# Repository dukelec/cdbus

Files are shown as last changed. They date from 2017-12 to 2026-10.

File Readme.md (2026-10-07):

[//]: # (IP Core for CDBUS Protocol)

CDBUS IP Core
=======================================
(This is the 8-bit version; for the 32-bit version, please switch to the corresponding branch.)

1. [CDBUS Protocol](#cdbus-protocol)
2. [Block Diagram](#block-diagram)
3. [Registers](#registers)
4. [Interface](#interface)
5. [Examples](#examples)
6. [Simulation](#simulation)
7. [Ready-to-Use Devices](#ready-to-use-devices)
8. [License](#license)

CDBUS is a simple protocol designed for serial ports and serial bus communication, commonly employed in RS-485 buses.
It utilizes hardware arbitration and other mechanisms to avoid data conflicts, allowing nodes to freely transmit and receive data packets,
thereby overcoming the limitations of single-master polling.

## CDBUS Protocol

CDBUS has a 3-byte header: `[src_addr, dst_addr, data_len]`, followed by user data, and concluding with a 2-byte CRC (identical to MODBUS CRC).

The CDBUS protocol at the byte level can be directly used for traditional serial communication,
such as traditional UART, RS-232, RS-485, and USB virtual serial ports.

The full CDBUS protocol at the bit level requires dedicated hardware controllers (or software emulation)
to achieve conflict avoidance, higher speeds, and strong real-time performance.

### Arbitration Mode (CDBUS-A)

* Introduces an arbitration mechanism, similar to the CAN bus, to automatically avoid conflicts.
* Supports dual baud rates for high-speed communication;
  the maximum baud rate of the high-speed phase is `sysclk` ÷ 3 (e.g. 50 Mbps for 150 MHz `sysclk`).
* Supports unicast, multicast and broadcast.
* The maximum user data size is 253 bytes.
* Hardware packing, unpacking, verification and filtering, reducing CPU load and development effort.
* Compatible with traditional RS-485 hardware (the arbitration function remains effective).

The protocol timing example, consisting of only one byte of user data:  
(You can configure the lengths of idle time and transmission permit time.)

protocol

Tips:
 - When a high-priority node needs to send unimportant data, its transmission permit time (TX_PERMIT_LEN) can be dynamically increased.

Arbitration example:

arbitration

Example waveforms for TX output and TX_EN pins:

arbitration

The RX data sampling point is at 1/2 bit; for TX readback, it's at 3/4 bit.

Lower-priority nodes back off during arbitration and retransmit after the bus is idle, until successful or cancelled by
the user.

### Break Sync Mode (CDBUS-BS)

In CDBUS-A mode, if the low-speed portion takes too long, it can become a bottleneck for communication efficiency.

To address this, single-rate peer-to-peer bus communication can be achieved using CDBUS-BS mode:

 - Different nodes have different configurations for the TX_PERMIT_LEN parameter, requiring sufficiently large differences to avoid conflicts.
 - If any node has pending data frames waiting to be sent before the transmission permit point, transmission starts from that point.
 - Otherwise, wait until the idle time exceeds MAX_IDLE_LEN. When there are pending data frames waiting for transmission,
   first send a break character to bring the bus out of the idle state.

arbitration

The CDBUS-BS mode is suitable for high-speed applications with few nodes, and is also well-suited to software implementation.

### Transparent Mode

For protocols other than CDBUS over a plain UART (8N1 only), e.g. MODBUS RTU,
the controller can pass raw frames through without header;
it works with the traditional half-duplex mode and the full-duplex mode, set DIV_HS equal to DIV_LS and keep FILTER at 0xff.
The CRC of CDBUS is the same as MODBUS, so the CRC is still appended and checked by hardware unless `CRC maintained by user` is set.

RX: bytes are collected into a page (up to 256 bytes), which is committed when the bus is idle for IDLE_WAIT_LEN;
RX_LEN is the byte count minus one. A frame with CRC error or longer than 256 bytes is dropped and flagged
like a broken CDBUS frame, or saved with `save broken frame` set (the page of an over-long frame is incomplete).
A single byte is dropped as noise.
In half-duplex mode, the echo of the own transmission is dropped unless the loopback bit is set.

TX: the page layout is the same as a CDBUS frame, `[reserved, reserved, data_len, data...]`, only the data (up to 253 bytes)
and the CRC are sent; with `CRC maintained by user`, the last two bytes come from the page as well,
data_len can still be 253: the bytes beyond the end of the page wrap around to the reserved bytes at the start.
The idle time between frames is IDLE_WAIT_LEN (half-duplex, if RX sees TX) plus TX_PERMIT_LEN plus TX_PRE_LEN,
which must be longer than the IDLE_WAIT_LEN of the receiver.

## Block Diagram

block_diagram

#### Operation

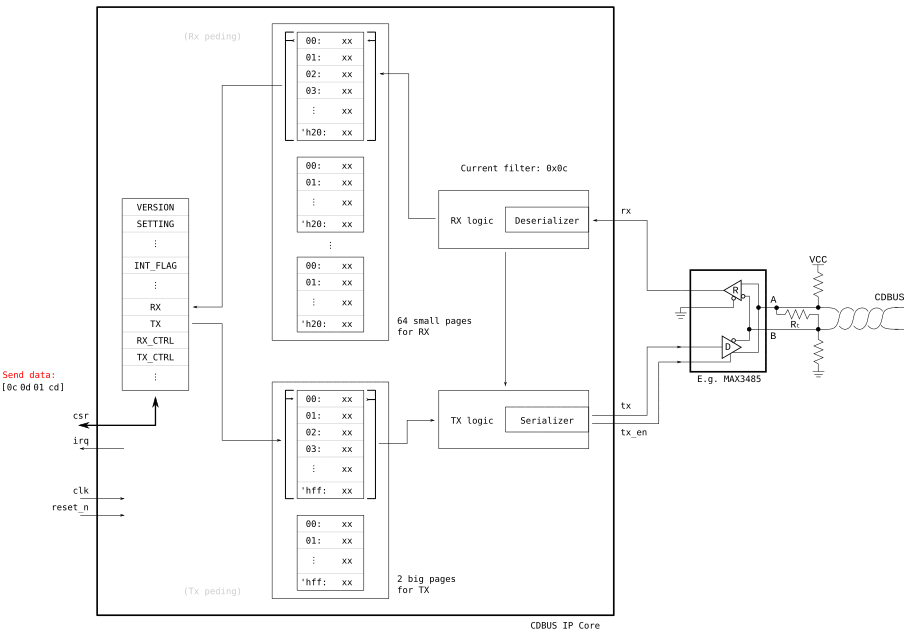
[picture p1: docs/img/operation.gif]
operation


## Registers

| Register Name |  Addr | Access | Default | Description (8-bit width by default if not specified)|
|---|---|---|---|---|
| VERSION |  0x00 | RD | 0x0f | Hardware version |
| SETTING |  0x02 | RD/WR  | 0x01 | Configuration |
| PIN_CFG |  0x03 | RD/WR  | 0x00 | Pin configuration |
| IDLE_WAIT_LEN |  0x04 | RD/WR  | 0x0a | Idle entry wait time |
| TX_PERMIT_LEN_L |  0x05 | RD/WR  | 0x14 | TX permit wait time (10 bits) |
| TX_PERMIT_LEN_H |  0x06 | RD/WR  | 0x00 | |
| MAX_IDLE_LEN_L |  0x07 | RD/WR  | 0xc8 | Max idle wait time, BS mode (10 bits) |
| MAX_IDLE_LEN_H |  0x08 | RD/WR  | 0x00 | |
| TX_PRE_LEN |  0x09 | RD/WR  | 0x01 | TX_EN pre-assert time (2 bits) |
| FILTER |  0x0b | RD/WR  | 0xff | Local address |
| DIV_LS_L |  0x0c | RD/WR  | 0x5a | Low-speed rate setting (16 bits) |
| DIV_LS_H |  0x0d | RD/WR  | 0x01 | |
| DIV_HS_L |  0x0e | RD/WR  | 0x5a | High-speed rate setting (16 bits) |
| DIV_HS_H |  0x0f | RD/WR  | 0x01 | |
| INT_MASK_L |  0x10 | RD/WR  | 0x00 | Interrupt mask (16 bits) |
| INT_MASK_H |  0x11 | RD/WR  | 0x00 | |
| INT_FLAG_L |  0x12 | RD | n/a | Status (16 bits) |
| INT_FLAG_H |  0x13 | RD | n/a | |
| RX_LEN |  0x14 | RD | n/a | Data length of the frame to be read, or frame_len - 1 |
| DAT |  0x15 | RD/WR  | n/a | Read & Write RX page |
| CTRL |  0x16 | WR | n/a | RX & TX control |
| DAT_HOLD |  0x17 | RD/WR  | n/a | Same as DAT, but keeps the page open |
| RX_ADDR |  0x18 | WR | n/a | Set the read position of the RX page |
| FILTER_M0 |  0x1a | RD/WR  | 0xff | Multicast filter0 |
| FILTER_M1 |  0x1b | RD/WR  | 0xff | Multicast filter1 |
| FILTER_MSK0 |  0x1c | RD/WR  | 0xff | Multicast mask0 |
| FILTER_MSK1 |  0x1d | RD/WR  | 0xff | Multicast mask1 |

To write a register with more than 8 bits, first write the high byte followed by the low byte.
The high byte can be omitted if it is 0.

Time unit: one bit period at the low-speed baud rate.

**SETTING:**

| FIELD | DESCRIPTION |
|--- |---|
| [5] | Save broken frame |
| [4] | CRC maintained by user |
| [3] | Transparent mode: keep own TX echo (loopback) |
| [2] | Transparent mode |
| [1:0] | Mode selection |

| [1] | [0] | DESCRIPTION |
|-----|-----|---|
| 0 | 0 | Traditional half-duplex mode |
| 0 | 1 | CDBUS-A mode (default) |
| 1 | 0 | CDBUS-BS mode |
| 1 | 1 | Full-duplex mode |

Transparent mode only works with mode 00 and 11.

**PIN_CFG:**

| FIELD | DESCRIPTION |
|--- |---|
| [3] | RX pin inversion |
| [2] | TX pin inversion |
| [1] | TX stays low for arbitration and break character  |
| [0] | Enable push-pull output for TX and TX_EN pin |

**TX_PRE_LEN:**

Example waveforms for TX output and TX_EN pins (TX_PRE_LEN = 1 bit):

arbitration

Not used in arbitration mode, nor for the break character automatically generated in BS mode.

**FILTERS:**

block_diagram

Addresses other than 255 may be used as multicast addresses.

**DIV_xx_x:**

Baud rate divider value:
DIV_xx[15:0] = sysclk ÷ baud_rate − 1

The minimum value is 2.

For single-rate operation, set DIV_HS to the same value as DIV_LS.

**INT_MASK:**

Output of irq = ((INT_FLAG & INT_MASK) != 0).

**INT_FLAG:**

| FIELD | DESCRIPTION |
|--- |---|
| [15] | 1: Bus not idle |
| [14] | 1: Bus idle |
| [13:8]  | Number of RX pages to read |
| [7] | 1: TX error (TX low, RX sampled high) |
| [6] | 1: TX collision detected |
| [5] | 1: TX page released by hardware |
| [4] | 1: Empty TX page available |
| [3] | 1: RX error (frame broken) |
| [2] | 1: RX lost (no empty RX page) |
| [1] | 1: Break character received |
| [0] | 1: RX page ready to read |

Reading this register will automatically clear bit7, bit6, bit3, bit2 and bit1.

If `save broken frame` is set, bit3 indicates whether the current page to be read is broken
(reading this register does not clear bit3).

The [13:8] field wraps around at 64: if bit0 is 1 while [13:8] reads 0,
there are 64 RX pages waiting to be read.

**RX_LEN:**

The default value of this register corresponds to the data_len of the frame to be read.  
If `save broken frame` is enabled, this register's value equals the size of the frame to be read minus one (including CRC).
In transparent mode, it is the size of the page minus one (including CRC).

For interfaces like SPI, when two or three bytes are read from the INT_FLAG_L register in a single transfer,
the first byte represents INT_FLAG_L, the second byte represents RX_LEN, and the third byte represents INT_FLAG_H.

**CTRL:**

| FIELD | DESCRIPTION |
|--- |---|
| [7] | Reset RX block |
| [4] | Release current RX page |
| [3] | Abort transmission and clear current TX page |
| [2] | Clear pending TX page |
| [1] | Send break character |
| [0] | Submit TX page |

For interfaces like SPI, the RX page is automatically released after a transfer that reads the DAT register,
while the TX page is automatically submitted after a transfer that writes to the DAT register.

**DAT_HOLD:**

An alias of DAT for interfaces like SPI: it reads and writes the same page at the same position,
but the page is not released or submitted when the transfer ends, and the position is kept for the next transfer.
This allows one page to be accessed across multiple transfers:
access the first parts through DAT_HOLD, then either access the last part through DAT (automatic finish),
or write bit4 or bit0 of the CTRL register (manual finish).
Transfers to other registers in between do not affect the kept position.

**RX_ADDR:**

Writing this register sets the byte offset for the next DAT or DAT_HOLD read within the current RX page,
to skip the unwanted part of a frame.
For interfaces like SPI, the page is kept open after the transfer that writes this register,
so the following read starts from the set position.

## Interface

```verilog
    parameter DIV_LS = 346,         // default: 115200 bps for 40MHz clk
    parameter DIV_HS = 346

    input           clk,            // core clock
    input           reset_n,        // async active-low reset
    input           chip_select,
    output          irq,            // interrupt output

    // read data is valid in the clock after csr_read, one byte per clock in a burst
    input   [4:0]   csr_address,
    input           csr_read,
    output  [7:0]   csr_readdata,
    input           csr_write,
    input   [7:0]   csr_writedata,

    // connect to external PHY chip, e.g. MAX3485
    input           rx,
    output          tx,
    output          tx_en
```

**chip_select:**

Besides the transfer-based behaviour described above for interfaces like SPI (enabled by `CD_CHIP_SELECT`),
`chip_select` gates the read port of the RX RAM to reduce power consumption:
the RX RAM is only read while it is high, so it must be high in the clock of a DAT read.
For SoC integration, drive it from the bus select of this peripheral, e.g. `psel` of APB or `hsel` of AHB,
or simply tie it high at the cost of the RX RAM being read every clock.

**Read timing:**

A read is taken at the clock edge where `csr_read` is high, and the data is valid in the clock after it,
as on a synchronous bus with one clock of read latency; `csr_address` must be kept until then.
`csr_read` is sampled every clock: each clock it is high is one read, so holding it high for N clocks
is a burst of N reads, one byte per clock. Since reading DAT advances the address and reading INT_FLAG_L
clears the flags, a host that stretches one access over several clocks (e.g. wait states) must assert
`csr_read` in only one of them.

## Examples

```python
    # Configuration
    
    write(REG_PIN_CFG, [0x01])                # Enable push-pull output

    # TX
    
    while (read(REG_INT_FLAG_L) & 0x10) == 0: # Ensure free TX page is available
        pass
    write(REG_DAT, [0x0c, 0x0d, 0x01, 0xcd])  # Write frame without CRC

    # RX
    
    while True:                               # Wait until RX page is ready
        val = read(REG_INT_FLAG_L, len=2)
        if (val[0] & 0x01) != 0:
            break
    data = read(REG_DAT, len=val[1]+3)
```

## Simulation
Install `iverilog` (>= v10) and `cocotb`, go to the `tests/` directory, and run `./test_all.sh` or `./test_all.sh test_xxx.py`.
(You can view the waveform `cdbus.vcd` with GTKWave.)

## Ready-to-Use Devices

The CDCTL controller family incorporates the CDBUS IP Core, providing peripheral interfaces such as SPI, I<sup>2</sup>C, and PCIe.  
For example, the tiny CDCTL-Bx module supports SPI and I<sup>2</sup>C interfaces:  
(The source code and gerber files for this module are fully open-source and located in the `example/` directory.)  
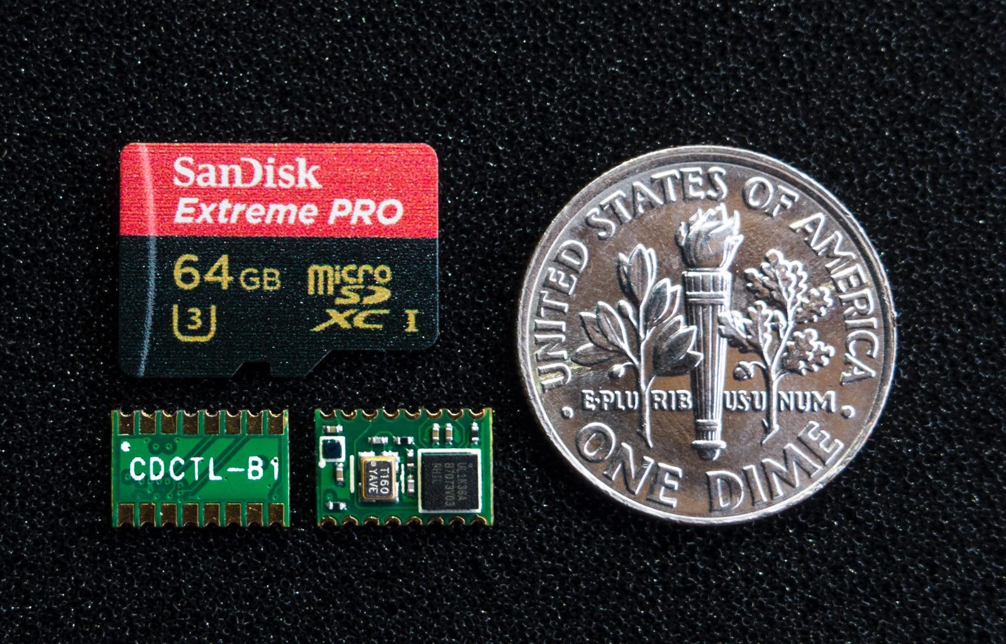
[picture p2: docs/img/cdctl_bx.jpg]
cdctl_bx


For a list of CDBUS-related ASIC chips, please refer to the [wiki](https://github.com/dukelec/cdbus/wiki) page.

Other related projects that may interest you:
 - CDBUS GUI: https://github.com/dukelec/cdbus_gui
 - CDNET: https://github.com/dukelec/cdnet

## License
```
This Source Code Form is subject to the terms of the CERN Open
Hardware Licence Version 2 - Strongly Reciprocal (CERN-OHL-S v2):
https://ohwr.org/cern_ohl_s_v2.txt (see the LICENSE file).
Notice: The CDBUS Exception (see the LICENSE_EXCEPTION file)
grants free commercial use in FPGAs and other programmable logic
devices; it does not extend to ASIC design or manufacturing.

Copyright (c) 2017-2026 DUKELEC, All rights reserved.
```

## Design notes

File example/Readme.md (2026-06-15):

CDBUS IP Example
=======================================
This CDCTL-B (or CDCTL-H) module project integrates an SPI (or I<sup>2</sup>C) interface with the CDBUS IP core.  
The following sections describe the communication protocol used by the SPI and I<sup>2</sup>C interfaces.

  



## SPI

Read or write depends on bit W/R̅:  
 - 0: Read
 - 1: Write

| FIELD | DESCRIPTION |
|--- |---|
| Ax | Register address |
| Wx | Write data |
| Rx | Read data |
| X | Don't care |

Read or write single byte:  


Burst read or write:  


## I<sup>2</sup>C

| FIELD | DESCRIPTION |
|--- |---|
| DAx | I<sup>2</sup>C device address, DA0 and DA1 set by I2C_ADDR_x pins |
| Ax | Register address |
| Wx | Write data |
| Rx | Read data |
| X | Don't care |
| D | ACK by device |
| H | ACK by host |
| N | Host does not ACK after reading the last byte |

### Write



### Read

Write register address first, then read back:  


Burst read back:  


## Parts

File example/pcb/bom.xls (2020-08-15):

Qty | Reference(s) | Value | Footprint | Datasheet
2 | C1, C2 | 1u | C0201
2 | C3, C4 | 10p | C0201
2 | C5, C6 | 100n | C0201
1 | R1 | 2K | R0201
1 | R2 | 10K | R0201
1 | R3 | 220 | R0201
1 | R4 | 1M | R0201
1 | U1 | ICE40UL1K-CM36A | CM36A
1 | U2 | TCR3DG12 | WCSP4E
1 | Y1 | 16M | XTAL_2016

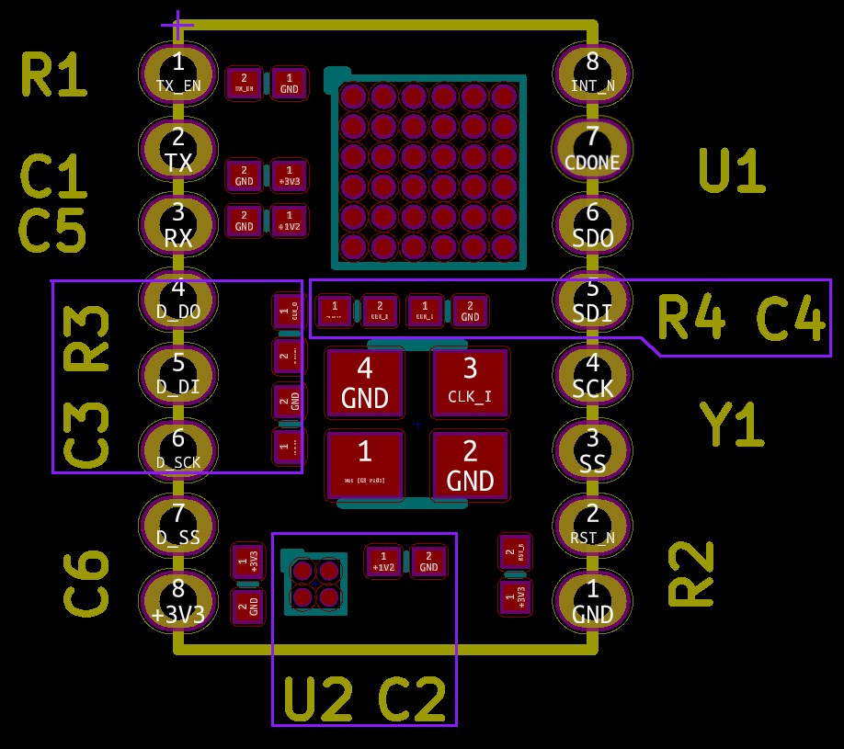
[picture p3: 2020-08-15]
example/pcb/cdctl_bx_component.png

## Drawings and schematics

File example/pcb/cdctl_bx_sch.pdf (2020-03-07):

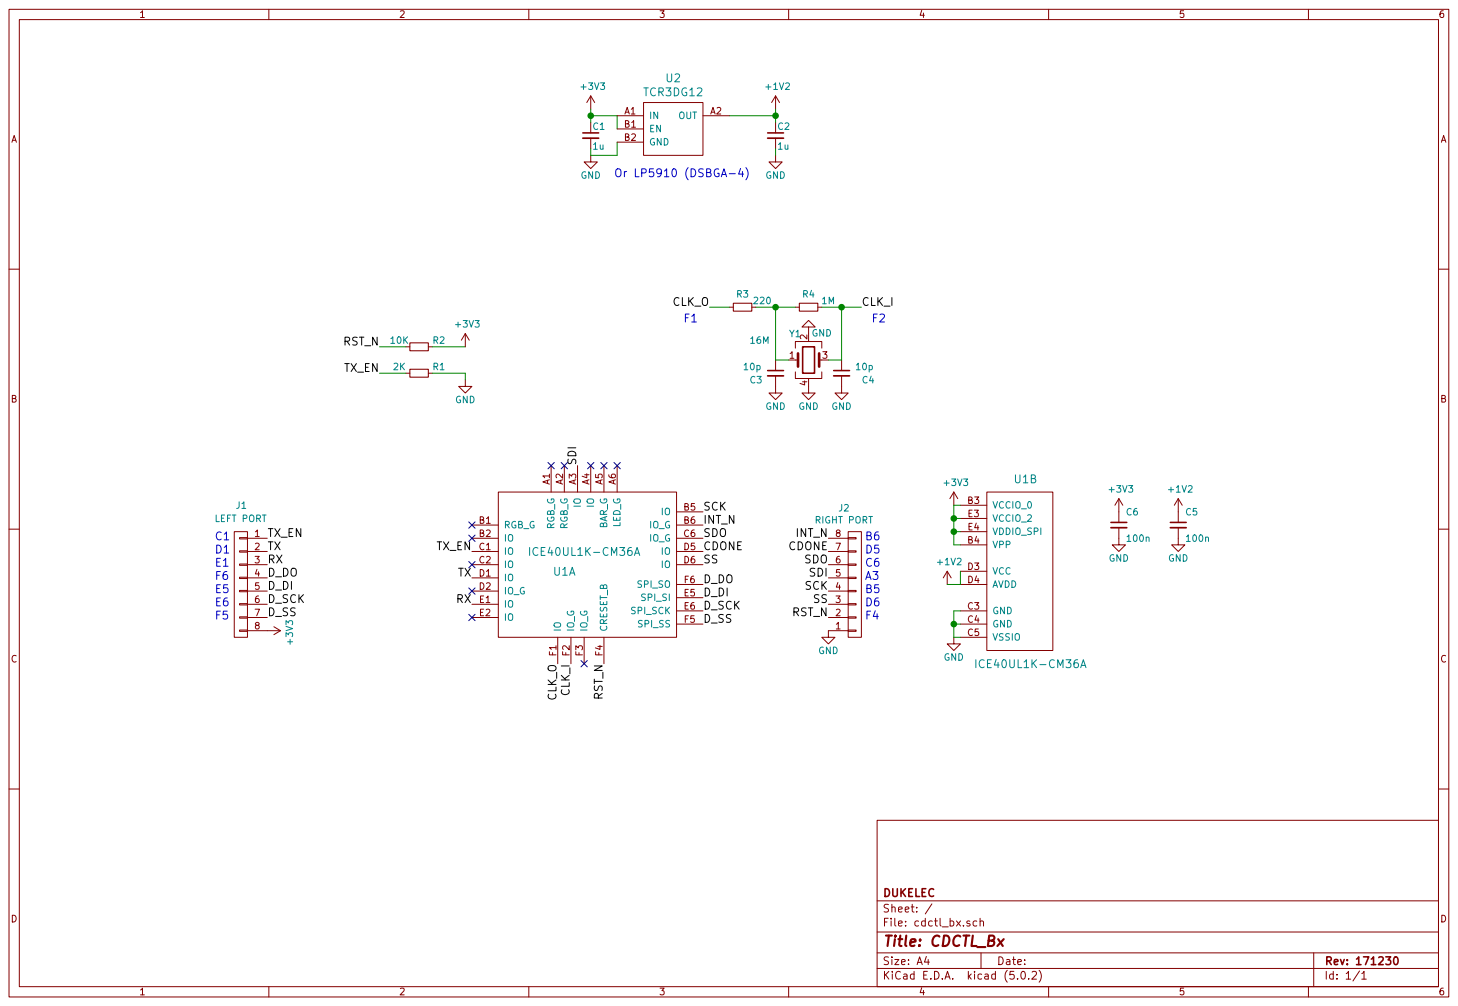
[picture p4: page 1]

File: cdctl_bx.sch Sheet: / DUKELEC

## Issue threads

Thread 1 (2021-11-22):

About the DIV_xx_x parameter

David7Pan, 2021-11-22:
Is there any way to reduce the minimum value of parameter DIV_xx_x from 2 to 1?
I try to figure it out, but there still some confused questions like :
Why the minimum value of parameter DIV_xx_x is 2?
What the INIT_VAL means in cd_baud_rate module？To adjust the phase ？
-------------
Blessing!

dukelec, 2021-11-22:
The theoretical minimum multiplier for oversampling is 3. (The DIV is counted from 0, so the minimal DIV value is 2.)

The following explains why oversampling is not feasible for 2. The waveform above is the 2x rising edge sampling clock, and the waveform below is the uart rx line:
```
   s   s   s   s   s
   1   2   3   4   5
   ┌─┐ ┌─┐ ┌─┐ ┌─┐ ┌─┐
 ──┘ └─┘ └─┘ └─┘ └─┘ └──

 ──────┐       ┌───────
       └───────┘
 idle    start    bit0    ...
```
If s2 is sampled to 0, then s3 is used as the middle to get the correct data.
But if s2 samples to 1, then s3 samples to 0, and the final sample value of s4 may be 0 or 1.
Unlike the internal communication of FPGA, the clock accuracy of the external communication varies from node to node, and with noise and jitter, 2x sampling is not guaranteed to be correct.

To achieve 3x oversampling, the logic is more complex than higher oversampling, and requires careful tuning of the data synchronization between modules. sync_3x and INIT_VAL are both for adjusting the phase.

David7Pan, 2022-06-02:
Thank you for your reply.
I got a new question, actually hoping to know, that in the cd_tx_ser module, why Arbitration Mode  do not need 'tx_pre_len', but  other modes need?

dukelec, 2022-06-02:
The total output data has three states: Strong 0, Strong 1 and Weak 1.

The tx_pre_len corresponds to strong 1 output, while strong 1 output is not allowed in arbitration phase, so there is no tx_pre_len in arbitration mode.

If there is no tx_pre_len when outputting data, there will be a delay in the beginning of the output data after it passes through the 485 interface chip:
```
 ttl output: ──────┐       ┌───────
                   └───────┘
 485 output: ───────┐      ┌───────
                    └──────┘
```
(Because the time required to enable the output of the 485 chip is much longer than the delay in data transfer. The specific time lengths can be found in the corresponding 485 chip manuals.)
(The above figure ignores the delay in data transfer, as it is relatively short.)

This delay can cause problems in high-speed communication, but the rate of arbitration stage is usually not more than 1Mbps, so it will not cause problems.

David7Pan, 2022-06-06:
When reach_max_idle ,BS mode will send a break character, why this character does not need tx_pre_len?  Will the delay cause the receiver got a wrong break character (be less than 10 bits) ?

dukelec, 2022-06-09:
Because there may be multiple nodes sending the break character at the same time. Similar to arbitration mode, strong 1 data is not allowed to be sent in case of possible data collisions, so tx_pre_len is not used.

The received data may be shorter than 10 bits, but this will not cause problems. This is because the purpose of sending the break character is to put the bus into a non-idle state.

HunterLiu0517, 2024-08-30:
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

Excuse me, I find that the signal of baud_sync (in module cd_tx_ser.v) is always 1, is there something wrong here?

HunterLiu0517, 2024-09-06:
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

Wyh " the rate of arbitration stage is usually not more than 1Mbps"?  Is there something wrong when the arbitration rate > 1Mbps?

dukelec, 2024-09-07:
@HunterLiu0517

1. During the arbitration phase, since weak 1s and strong 0s are being sent, the transition of the line from 0 to 1 takes slightly longer than the transition from 1 to 0. If the baud rate is very high, the bit width difference between 0 and 1 may become too large.

2. Due to the transmission delay caused by the transceiver and the line, if two nodes are transmitting data simultaneously and the baud rate is too high, by the time each node reaches three-quarters of a bit, it may fail to read the corresponding bit from the other node. Instead, it might read the previous bit from the other node or itself.

HunterLiu0517, 2024-09-12:
Thanks for your reply.

dukelec, 2024-10-17:
@HunterLiu0517

This piece of code is used to simulate the 485 interface circuit and the state of the 485 bus. A single wire, bus_a, is used here to represent the current state of the 485 bus.

In typical 485 circuits, the /RE and DE pins are usually controlled together, so that when transmitting, the receiving function is disabled. However, we only need to fix the /RE pin to a low level and control only the DE pin. This way, 'RX=TX' can be achieved during the transmission phase. You can check the wiring method of the 485 transceiver on the right side of the Block Diagram in the Readme.

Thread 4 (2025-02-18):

Arbitration section (SRC_ADDR 0x55) Differential output anomaly?

HunterLiu0517, 2025-02-18:
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

As shown in the figure above, the 485 transceiver TX input is normal (TTL level), but the differential output is abnormal (arbitration segment 0x55), and the other segments are normal.

HunterLiu0517, 2025-02-18:
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

Pink is the differential output signal.

dukelec, 2025-02-19:
I suggest capturing TX, OE (TX_EN), and A signals simultaneously to check if TX_EN lags too much behind TX, as this may relate to FPGA timing constraints.

Also, which interface chip are you using? Some chips may have a significant difference between `driver propagation delay` and `driver disable/enable time (receiver enabled)`.

dukelec, 2025-02-20:
The next* branch adds a configuration: setting bit7 of the SETTING register avoids this issue and lowers interface chip requirements by keeping TX low longer during arbitration.

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

HunterLiu0517, 2025-02-20:
> I suggest capturing TX, OE (TX_EN), and A signals simultaneously to check if TX_EN lags too much behind TX, as this may relate to FPGA timing constraints.
>
> Also, which interface chip are you using? Some chips may have a significant difference between `driver propagation delay` and `driver disable/enable time (receiver enabled)`.

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
During transmitting arbitration section (SRC_ADDR), TX_EN is disabled when TX=1.  And if TX_EN disabled, output signals (A or B) is "Z", no matter what level TX is.（as follow figure）

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

dukelec, 2025-02-20:
When TX_EN is off, it is normal for AB outputs to be in a "Z" state. At this time, the bus pull-up and pull-down resistors pull AB to a weak 1 state.

If the interface chip delays disabling AB outputs after TX_EN goes low, it may produce a strong 1 glitch. Small glitches don’t affect communication, but the one you observed is too wide.

HunterLiu0517, 2025-02-20:
> The next* branch adds a configuration: setting bit7 of the SETTING register avoids this issue and lowers interface chip requirements by keeping TX low during arbitration.
>
> 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

Hi dukelec, i want to know when you'ii release the new branch. And will this change affect the arbitration mechanism, When TX conflicts?
And the transceiver  interface chip type we are using is SN65176BDR.

dukelec, 2025-02-20:
The commit was submitted just last night.
It only eliminates the strong 1 glitch and will not affect the arbitration mechanism.

The `tPHZ Output disable time from high level` of the chip you're using is a bit large.
The latest commit is suitable for the chip you selected.
For reference, you can compare the parameters with those of the SN65HVD75 and THVD1450DR.

HunterLiu0517, 2025-02-21:
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
Based on your suggestion, I have optimized the RC parameters of the circuit, and now the waveforms of TX, TX_EN and signal A are shown in the figure above.  Now  the waveform has been improved significantly, and most of the glitches have been eliminated.
However, in the arbitration stage, the differential signal output is high resistance, and the difference between A-B is small. **If the signal in this stage is subjected to external interference, is it possible that the AB output will change from weak 1 state to weak 0 state, resulting in communication failure**?
I'd like to know your opinions and suggestions. Thanks!

dukelec, 2025-02-21:
What RC parameter modifications have you made?

I noticed that you haven't enabled the latest feature I submitted. Simply adjusting the pull-up and pull-down resistors will not eliminate the strong "1" glitch.

It is possible that the TX_EN and TX signals from the FPGA are not synchronized, which could be causing this issue. This desynchronization can vary with each synthesis, especially in the absence of SDC constraints.

5V ÷ (330+330+120) × 120 = 0.769230769 V
This voltage difference is significantly higher than the 200mV specified by RS485, ensuring reliable communication.

Traditional RS485 also maintains this voltage difference when idle, so there is no need to worry about interference data being received due to a low differential voltage.

If you want to further increase the voltage difference, you can decrease the resistance value of the pull-up and pull-down resistors, increase the resistance value of the termination resistor, or use AC Termination. For example, setting cTERM to 100pF could work. For short-distance transmission, the termination resistor is often not needed.

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

HunterLiu0517, 2025-02-21:
Yes, totally agree. This issue was caused for TX_EN and TX signals are not synchronized. (On my board, TX and TX_EN are synchronized which are output by FPGA. However, when they pass through the intermediate circuit (such as the driver buffer, etc.), the circuit parameters (RC) are different, resulting in the output to the 485 transceiver chip end (SN65176BDR) is not synchronized.
Now TX_EN and TX signals are synchronized, and the strong "1" glitch can be eliminated as above.

dukelec, 2025-02-21:
If there are no longer any strong "1" glitches, you don't need to merge the latest commit (8ccf6098). Even if you do merge it and enable the feature, there will be no noticeable difference in usage.

Your pull-up/down resistor is a bit large; it's recommended to use 330Ω:
(The 330Ω pull-up/pull-down should be used only at a single node.)

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

HunterLiu0517, 2025-02-21:
Got it. Thank you.
And the reason why I choose 1kΩ pull-up/pull-down is that my system contains up to 10 nodes, and they are networked via 485. If the pull-up/pull-down resistance is too small (Rs), the final resistance value after 10 nodes are connected will be smaller(Rtotal=1/10 *Rs), which will make the drive current flowing through the interface chip relatively large.
In addition for single node, the differential output voltage ΔU(A-B):
ΔU=5*120/(120+1000+1000) =0.2830V > 0.2V, This voltage difference is higher than the 200mV specified by RS485, ensuring reliable communication.

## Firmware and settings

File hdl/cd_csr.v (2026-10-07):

/*
 * This Source Code Form is subject to the terms of the CERN Open
 * Hardware Licence Version 2 - Strongly Reciprocal (CERN-OHL-S v2):
 * https://ohwr.org/cern_ohl_s_v2.txt (see the LICENSE file).
 * Notice: The CDBUS Exception (see the LICENSE_EXCEPTION file)
 * grants free commercial use in FPGAs and other programmable logic
 * devices; it does not extend to ASIC design or manufacturing.
 *
 * Copyright (c) 2017-2026 DUKELEC, All rights reserved.
 *
 * Author: Duke Fong <d@d-l.io>
 */

module cd_csr
    #(
        parameter VERSION = 8'h0f,
        parameter DIV_LS = 346, // default: 115200 bps for 40MHz clk
        parameter DIV_HS = 346
    )(
        input               clk,
        input               reset_n,
        output reg          irq,
`ifdef CD_CHIP_SELECT
        input               chip_select,
`endif

        input       [4:0]   csr_address,
        input               csr_read,
        output reg  [7:0]   csr_readdata,
        input               csr_write,
        input       [7:0]   csr_writedata,

        output reg          tx_en_inner,
        output reg          rx_invert,
        output              full_duplex,
        output              break_sync,
        output              arbitration,
        output reg          not_drop,
        output reg          user_crc,
        output reg          raw,        // transparent uart mode
        output reg          loopback,   // raw mode: keep own tx echo
        output reg          tx_invert,
        output reg          tx_push_pull,

        output reg  [7:0]   idle_wait_len,
        output reg  [9:0]   tx_permit_len,
        output reg  [9:0]   max_idle_len,
        output reg  [1:0]   tx_pre_len,
        output reg  [7:0]   filter,
        output reg  [7:0]   filter_m0,
        output reg  [7:0]   filter_m1,
        output reg  [7:0]   filter_msk0,
        output reg  [7:0]   filter_msk1,
        output reg  [15:0]  div_ls,
        output reg  [15:0]  div_hs,

        output reg          rx_clean_all,
        output reg          rx_ram_rd_done,
        output reg  [7:0]   rx_ram_rd_addr,
        input       [7:0]   rx_ram_rd_byte,
        input       [7:0]   rx_ram_rd_len,
        input               rx_ram_rd_err,
        input               rx_error,
        input               rx_ram_lost,
        input               rx_break,
        input               rx_pending,
        input       [5:0]   rx_pend_len,
        input               bus_idle,

        input               tx_ram_full,
        output              tx_ram_wr_en,
        output reg  [7:0]   tx_ram_wr_addr,
        output reg          tx_ram_wr_done,
        output reg          tx_abort,
        output reg          tx_drop,
        output reg          has_break,
        input               ack_break,
        input               tx_pending,
        input               cd,
        input               tx_err
    );

localparam
    REG_VERSION         = 'h00,
    REG_SETTING         = 'h02,
    REG_PIN_CFG         = 'h03,
    REG_IDLE_WAIT_LEN   = 'h04,
    REG_TX_PERMIT_LEN_L = 'h05,
    REG_TX_PERMIT_LEN_H = 'h06,
    REG_MAX_IDLE_LEN_L  = 'h07,
    REG_MAX_IDLE_LEN_H  = 'h08,
    REG_TX_PRE_LEN      = 'h09,
    REG_FILTER          = 'h0b,
    REG_DIV_LS_L        = 'h0c,
    REG_DIV_LS_H        = 'h0d,
    REG_DIV_HS_L        = 'h0e,
    REG_DIV_HS_H        = 'h0f,
    REG_INT_MASK_L      = 'h10,
    REG_INT_MASK_H      = 'h11,
    REG_INT_FLAG_L      = 'h12,
    REG_INT_FLAG_H      = 'h13,
    REG_RX_LEN          = 'h14,
    REG_DAT             = 'h15,
    REG_CTRL            = 'h16,
    REG_DAT_HOLD        = 'h17,
    REG_RX_ADDR         = 'h18,
    REG_FILTER_M0       = 'h1a,
    REG_FILTER_M1       = 'h1b,
    REG_FILTER_MSK0     = 'h1c,
    REG_FILTER_MSK1     = 'h1d;

reg tx_error_flag;
reg cd_flag;
reg rx_error_flag;
reg rx_lost_flag;
reg rx_break_flag;

reg [1:0] mode_sel;
reg [15:0] int_mask;
wire [15:0] int_flag = {~bus_idle, bus_idle, rx_pend_len,
                        tx_error_flag, cd_flag, ~tx_pending, ~tx_ram_full,
                       (not_drop ? rx_ram_rd_err : rx_error_flag), rx_lost_flag, rx_break_flag, rx_pending};
reg [7:0] h_val_bkup;
reg flag_rd_d;      // read data is valid in the clock after csr_read: the side effects of
                    // reading INT_FLAG_L (shift, clear) are delayed to keep that clock intact

`ifdef CD_CHIP_SELECT
reg [1:0] chip_select_d;
reg has_read_rx;    // DAT accessed in this transfer: auto finish at end
reg has_write_tx;
reg flag_cleared;   // INT_FLAG_L read in this transfer: clear the flags only once,
                    // the later bytes of a burst must not clear events after the snapshot
reg rx_open;        // set by DAT_HOLD, cleared by DAT or CTRL: keep page and address across transfers
reg tx_open;
reg [23:0] int_flag_shift;
reg [15:0] int_flag_snapshot;
`endif

wire is_dat_addr = (csr_address == REG_DAT) || (csr_address == REG_DAT_HOLD);
assign tx_ram_wr_en = is_dat_addr ? csr_write : 1'b0;

assign full_duplex = mode_sel == 2'd3;
assign break_sync = mode_sel == 2'd2;
assign arbitration = mode_sel == 2'd1;


always @(*)
    case (csr_address)
        REG_VERSION:
            csr_readdata = VERSION;
        REG_SETTING:
            csr_readdata = {2'd0, not_drop, user_crc, loopback, raw, mode_sel};
        REG_PIN_CFG:
            csr_readdata = {4'd0, rx_invert, tx_invert, tx_en_inner, tx_push_pull};
        REG_IDLE_WAIT_LEN:
            csr_readdata = idle_wait_len;
        REG_TX_PERMIT_LEN_L:
            csr_readdata = tx_permit_len[7:0];
        REG_TX_PERMIT_LEN_H:
            csr_readdata = {6'd0, tx_permit_len[9:8]};
        REG_MAX_IDLE_LEN_L:
            csr_readdata = max_idle_len[7:0];
        REG_MAX_IDLE_LEN_H:
            csr_readdata = {6'd0, max_idle_len[9:8]};
        REG_TX_PRE_LEN:
            csr_readdata = {6'd0, tx_pre_len};
        REG_FILTER:
            csr_readdata = filter;
        REG_DIV_LS_L:
            csr_readdata = div_ls[7:0];
        REG_DIV_LS_H:
            csr_readdata = div_ls[15:8];
        REG_DIV_HS_L:
            csr_readdata = div_hs[7:0];
        REG_DIV_HS_H:
            csr_readdata = div_hs[15:8];
        REG_INT_MASK_L:
            csr_readdata = int_mask[7:0];
        REG_INT_MASK_H:
            csr_readdata = int_mask[15:8];
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

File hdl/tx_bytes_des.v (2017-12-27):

/*
 * This Source Code Form is subject to the terms of the Mozilla
 * Public License, v. 2.0. If a copy of the MPL was not distributed
 * with this file, You can obtain one at https://mozilla.org/MPL/2.0/.
 * Notice: The scope granted to MPL excludes the ASIC industry.
 *
 * Copyright (c) 2017 DUKELEC, All rights reserved.
 *
 * Author: Duke Fong <duke@dukelec.com>
 */

module tx_bytes_des (
        input               clk,
        input               reset_n,

        // control center
        input       [15:0]  period_ls,  // low speed
        input       [15:0]  period_hs,  // high speed
        input               user_crc,
        input               arbitrate,
        input       [1:0]   tx_en_delay,
        output reg          cd,         // collision detect
        output reg          cd_err,

        output reg          tx,
        output reg          tx_en,

        // pp_ram
        input               unread,
        input       [7:0]   data,
        output wire [7:0]   addr,
        output reg          read_done,

        // rx_ser
        input               tx_permit,

        input               rx
    );


// FSM

reg [3:0] state;
localparam
    WAIT            = 4'b0001,
    DELAY_HEAD      = 4'b0010,
    DELAY_HEAD_END  = 4'b0100,
    DATA            = 4'b1000;

always @(posedge clk or negedge reset_n)
    if (!reset_n) begin
        state <= WAIT;
    end
    else begin

        case (state)
        WAIT: begin
            if (tx_permit && unread)
                state <= arbitrate ? DATA : DELAY_HEAD;
        end

        DELAY_HEAD: begin
            if (delay_cnt == tx_en_delay)
                state <= DELAY_HEAD_END; // reset period_cnt
        end

        DELAY_HEAD_END: begin
            state <= DATA;
        end

        DATA: begin
            if (cd || (is_last_byte && byte_inc))
                state <= WAIT;
        end

        default: state <= WAIT;
        endcase
    end


// period_cnt

reg hs_flag;

reg bit_inc;
reg bit_mid;

wire [15:0] period_cur = hs_flag ? period_hs : period_ls;
reg [15:0] period_cnt;

always @(posedge clk or negedge reset_n)
    if (!reset_n) begin
        period_cnt <= 1;
        bit_inc <= 0;
        bit_mid <= 0;
    end
    else begin
        bit_inc <= 0;
        bit_mid <= 0;

        if (state == WAIT || state == DELAY_HEAD_END) begin
            period_cnt <= 1;
        end
        else begin
            period_cnt <= period_cnt + 1'd1;

            if (period_cnt == period_cur - period_cur[15:2]) // at 3/4 position of bit
                bit_mid <= 1;

            if (period_cnt >= period_cur) begin
                period_cnt <= 0;
                bit_inc <= 1;
            end
        end
    end


// delay_cnt

reg [1:0] delay_cnt;

always @(posedge clk or negedge reset_n)
    if (!reset_n) begin
        delay_cnt <= 0;
    end
    else begin
        if (state == WAIT)
            delay_cnt <= 0;
        else if (bit_inc)
            delay_cnt <= delay_cnt + 1'b1;
    end


// bits_ctrl

reg is_crc_byte;
reg is_last_byte;
reg bit_finished;
reg crc_data_clk;
reg [7:0] tx_byte;
wire [9:0] tx_data = {1'b1, tx_byte, 1'b0};

reg byte_inc;

reg [3:0] bit_cnt; // range: [0, 9]
reg tx_en_dynamic;

always @(posedge clk or negedge reset_n)
    if (!reset_n) begin
        hs_flag <= 0;
        crc_data_clk <= 0;
        cd <= 0;
        byte_inc <= 0;
        bit_cnt <= 0;
        bit_finished <= 0;
        tx_en_dynamic <= 1;

        tx <= 1;
        tx_en <= 0;
    end
    else begin
        crc_data_clk <= 0;
        cd <= 0;
        byte_inc <= 0;

        if (state != DATA) begin
            hs_flag <= 0;
            bit_cnt <= 0;
            tx <= 1;
            tx_en <= (state != WAIT && state != DATA);
            bit_finished <= 0;
            tx_en_dynamic <= 1;
        end
        else if (!bit_finished) begin

            tx <= tx_data[bit_cnt];
            tx_en <= (tx_en_dynamic && tx_data[bit_cnt] && arbitrate) ? 0 : 1;

            if (tx_en_dynamic && arbitrate && bit_mid) begin
                if (tx && !rx)
                    cd <= 1;
                else if (bit_cnt == 9) begin
                    tx_en <= 1; // advance 0.5 bit active tx_en
                    tx_en_dynamic <= 0;
                end
            end

            if (bit_inc) begin
                crc_data_clk <= (bit_cnt != 0 && bit_cnt != 9 && !is_crc_byte) ? 1 : 0;
                bit_cnt <= bit_cnt + 1'd1;
                if (bit_cnt == 9) begin
                    hs_flag <= 1;
                    bit_cnt <= 0;
                    byte_inc <= 1;
                    if (is_last_byte)
                        bit_finished <= 1;
                end
            end
        end
    end


// bytes_ctrl

wire [15:0] crc_data;

reg [8:0] byte_cnt;
assign addr = byte_cnt[7:0];
reg [7:0] data_len; // backup 3rd byte

always @(posedge clk or negedge reset_n)
    if (!reset_n) begin
        byte_cnt <= 0;
        data_len <= 0;
        is_crc_byte <= 0;
        is_last_byte <= 0;
        tx_byte <= 0;
    end
    else begin

        if (state != DATA) begin
            byte_cnt <= 0;
            data_len <= 0;
            is_crc_byte <= 0;
            is_last_byte <= 0;
        end
        else begin

            tx_byte <= data;

            if (byte_cnt == 2)
                data_len <= data;

            // we have enough time to change the byte which send at second bit
            else if (byte_cnt == data_len + 3) begin
                if (!user_crc)
                    tx_byte <= crc_data[7:0];
                is_crc_byte <= 1;
            end
            else if (byte_cnt == data_len + 4) begin
                if (!user_crc)
                    tx_byte <= crc_data[15:8];
                is_last_byte <= 1;
            end

            if (byte_inc)
                byte_cnt <= byte_cnt + 1'd1;
        end
    end


// cd_err and read_done

reg [1:0] retry_cnt;

always @(posedge clk or negedge reset_n)
    if (!reset_n) begin
        retry_cnt <= 0;
        read_done <= 0;
        cd_err <= 0;
    end
    else begin
        read_done <= 0;
        cd_err <= 0;

        if (cd) begin
            retry_cnt <= retry_cnt + 1'd1;
            if (retry_cnt == 2'b11) begin
                read_done <= 1;
                cd_err <= 1;
                // retry_cnt becomes 0 at next time
            end
        end
        else if (is_last_byte && byte_inc) begin
            read_done <= 1;
            retry_cnt <= 0;
        end
    end


serial_crc tx_crc_m(
    .clk(clk),
    .reset_n(reset_n),
    .clean(state != DATA),
    .data_clk(crc_data_clk),
    .data_in(tx),
    .crc_out(crc_data)
);

endmodule

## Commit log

2017-12-24 rx_bytes: return to INIT state at the end of each frame
2017-12-24 tx: reset retry_cnt if no collision detected
    [tx_bytes_des.v]
2018-06-14 rx: fix bugs about save broken frame: - RX_PAGE_FLAG's value is the pointer of last received byte +1 when timeout; - When timeout in promiscuous mode, two pages are reported.
2018-06-14 tx: avoid send empty frame even when tx_permit is always true
2018-08-27 increase multicast filter to 2
2020-03-12 rx: stop receiving after receiving break (This bug will cause nodes to be out of sync in BS mode and at high rates, because occasionally data jitter will continue to receive one byte.)
    example: SPI supports 3-wire mode
    [cd_csr.v, test_cdctl_bx.py]
2020-08-15 Add production files to the cdctl-b example.
    [bom.xls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]
2021-03-03 Add test case for break character tx and rx
2021-03-03 Fix tx stop bit readback comparison Now, it is safe to send break in any mode
    [cd_csr.v]
2022-08-06 Tests: fix deprecation warning 'dut.handle = value' of cocotb
    [test_cdctl_bx.py]
2022-08-08 Add int_flag_snapshot to avoid metastability
    [cd_csr.v]
2023-08-12 RX: drop frame if user data is great than 253 bytes
2023-08-12 RX buffer supports caching much more small frames
2023-08-12 Replace rx_page_flag to frame_len
    [cd_csr.v]
2023-08-12 Replace rx_page_flag to data_len or frame_len
    [cd_csr.v, test_cdctl_bx.py]
2023-08-12 Rx des: output crc_eq_zero instead of crc_data
2023-08-12 The spi frequency can now exceed the sys clock
2023-08-12 Optionally, bus_busy or bus_idle interrupts can be enabled
2024-07-11 Reduce spi sdo latency
2024-09-20 TX_EN can act as TX pin, supports single-wire push-pull UART bus
2024-09-21 Supports RX pin inversion
2025-04-19 Simplify SPI and improve its speed
2025-04-30 Fix QSPI metastability-related bug
    [cd_csr.v, test_cdctl_qspi.py, test_cdctl_spi.py]
2025-10-31 Add FILTER_MSKx registers
2026-01-21 Update readme, replace receive filter flow table with an image
2026-06-16 Fix rx_ram unread_len miscount on concurrent commit/retire
    [cd_csr.v]
2026-07-02 Fix stale wr_cancel in rx_ram and manual break stall in BS mode
2026-07-02 Update I2C: align with chip-select semantics, add test case
2026-07-02 Fix CSR event CDC glitches for SPI/QSPI, sync reset release, register irq
    [cd_csr.v]
2026-07-13 SPI/QSPI: cross event by toggle instead of pulse
    A pulse as narrow as one sck period may be missed by the clk domain
    sampling when sck approaches clk. Toggle once per event instead,
    the level persists until the next event and can never be missed.
    - toggles reset only by reset_n, an async clear by spi_reset_n
    would be taken as an extra event by the clk domain
    - qspi: unify the event path of normal and advance modes
2026-07-13 SPI: unify event toggling with QSPI, drop negedge event sampling
2026-08-15 Switch licence to CERN-OHL-S v2 with CDBUS Exception
    Replace MPL-2.0 with CERN Open Hardware Licence v2 - Strongly
    Reciprocal. The CDBUS Exception grants free commercial use in FPGAs
    and other programmable logic devices; ASICs and any other ICs whose
    function is fixed at manufacture are excluded and remain governed by
    the unmodified CERN-OHL-S v2 terms.
    [cd_csr.v]
2026-09-28 Add DAT_HOLD register to access one page across multiple transfers
    DAT_HOLD (0x17) is an alias of DAT for chip-select interfaces like SPI:
    it accesses the same page at the same position, but the page is not
    released or submitted when the transfer ends and the position is kept.
    Access the first parts through DAT_HOLD, then finish either through
    DAT (auto) or by CTRL bit4 / bit0 (manual).
    - rx_open / tx_open: set by DAT_HOLD, cleared by DAT or CTRL, gate the
    address reset during chip-select idle
    - CD_CSR_NO_LATENCY: undo the pre-read address increment at the end of
    a transfer when the RX page is kept open
    - CTRL manual finish now also resets the address in CD_CHIP_SELECT builds
    - add test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
    [cd_csr.v, test_cdctl_spi.py]
2026-09-28 Add RX_ADDR register to set the read position of the RX page
    Writing RX_ADDR (0x18) sets the byte offset for the next DAT or
    DAT_HOLD read, to skip the unwanted part of a frame. For chip-select
    interfaces the page is kept open after the transfer, so the following
    read starts from the set position.
    [cd_csr.v, test_cdctl_spi.py]
2026-10-06 Add transparent mode for raw UART data and split pin config into PIN_CFG
    SETTING (0x02) now holds the protocol bits: mode[1:0], transparent mode,
    loopback, user CRC, save broken frame. The pin bits move to PIN_CFG (0x03):
    push-pull, TX keep low, TX invert, RX invert.
    Transparent mode passes 8N1 frames through without header and filter,
    e.g. for MODBUS RTU, whose CRC is the same as CDBUS:
    - RX commits a page (up to 256 bytes) on idle, RX_LEN is len - 1; a frame
    with CRC error is dropped or saved like a broken CDBUS frame
    - TX page is [reserved, reserved, data_len, data...], only the data and the
    CRC are sent, the CRC path is shared with the CDBUS frame
    - own echo is dropped in half-duple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
    [cd_csr.v]
2026-10-07 Fix INT_FLAG burst re-clear, raw RX over-length and NO_LATENCY-only build
    - CD_CHIP_SELECT: a burst read of INT_FLAG_L pulses csr_read once per
    byte; only the first read of a transfer clears the sticky flags, so an
    event between the bytes is no longer lost (flag_cleared)
    - transparent mode: a frame longer than 256 bytes is flagged as broken
    (raw_too_long) instead of being committed as a valid page
    - CD_CSR_NO_LATENCY without CD_CHIP_SELECT: ram_pre_read was only declared
    under CD_CHIP_SELECT; the pre-read variant is now limited to that build
    (CD_CSR_PRE_READ), the other keeps the ram address one byte ahead while
    DAT is read (CD_CSR_RD_AHEAD) so zero-wait bursts return each byte o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
    [cd_csr.v]
2026-10-07 Define CSR reads with one clock of latency, drop CD_CSR_NO_LATENCY
    A read is taken at the clock edge where csr_read is high and the data is
    valid in the clock after it, as on a synchronous bus; DAT bursts take one
    byte per clock since the RX RAM output is already one clock behind the
    address. The side effects of reading INT_FLAG_L (shift, flag clear) are
    delayed by one clock (flag_rd_d), so both same-clock and next-clock
    sampling see the value before the shift.
    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
2026-11-12 Add CRC mode to the SPI, QSPI and I2C interfaces
    With bit0 of the chip-level register INTF_CFG (0x38) set, every transfer
    carries N-1 and a CRC16. A register write takes effect only after the CRC
    check, a rejected DAT write is not submitted, and each accepted write
    toggles the status byte returned by the next read.
    With CD_CSR_CRC the core gets two inputs: csr_crc_en stops reads from
    clearing INT_FLAG (write 1 to INT_FLAG_L instead) and from releasing the
    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
2026-11-12 Replace the dirty bitmap of rx_ram by a frame counter
    Frames follow one another from rd_sel to wr_sel, so a write can only run
    into the block at rd_sel, and only while frames are pending. The behaviour
    is the same at every clock, with about a fifth less logic in the core and
    a shorter critical path.
    While nothing is pending rd_sel follows wr_sel: a flipped bit in a pointer
    or in the count no longer blocks the buffer until it is reset.
    The Readme tells when an RX page may be released.
2026-11-13 Ignore short low glitches on RX
    A low that is high again at the mid-bit sample of the start bit is noise:
    the receiver waits for the next start bit instead of for idle, so a glitch
    no longer loses the next frame, or the current one between two bytes.
    bus_idle is unchanged, it still returns IDLE_WAIT_LEN after the glitch:
    the TX timing and the BS slots stay as before.
    Covered by test_noise_rx.
2026-11-13 Let raw frames span pages, leave the CRC to the host
    In raw mode the hardware neither appends nor checks a CRC. An RX page holds
    up to 255 bytes: a full page is committed at once and the frame goes on in
    the next page; a shorter page, an empty one after a full page, ends it.
    A TX page that is ready when the previous one is sent follows it in the
    same frame.
    The address filter now only sets the drop flag: the echo of a short raw
    frame ending after the transmission (3 clocks per bit) was kept.
2026-11-13 Align the RX baud counter for a frame starting as the bus becomes idle
    baud_sync was only set after one clock in BUS_IDLE. A start bit seen on that
    clock, or on the clock the idle wait ended, was sampled with the phase left
    over from counting idle bits, up to two clocks off: frames were lost at 3 to
    6 clocks per bit.
    The counter is now held from the first idle clock, and starts one count
    ahead when the start bit is already there on the clock the idle wait ends:
    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
2026-11-13 Fix the TX stall at max idle, count the pending pages of tx_ram
    The TX wait stopped counting at max idle even before the permit point:
    with TX_PERMIT_LEN above MAX_IDLE_LEN outside BS mode the node never
    sent, and a flipped bit of its flags on an idle bus kept it silent until
    another node sent (for good in full-duplex mode).
    tx_ram counts the pending pages instead of keeping two pointers and two
    flags. It behaves the same at every clock, but a flipped bit no longer
    puts the two pages out of step until a reset.
    Covered by test_soft_error.
2026-11-13 Keep TX low around breaks with PIN_CFG bit1, fix it for BS mode slots
    Outside arbitration mode tx_en_a was only set 2 bits after a break: with
    bit1, a BS node that always sent in its slot put out its frames as a
    constant low. tx_en_a is now set whenever no hold-off time is running,
    also after a reset or a mode switch.
    TX_EN takes effect with a delay at the transceiver, so TX is now low
    before and after every break with bit1: all breaks of BS mode go through
    BS_PRE like the one sent at max idle (without bit1, a break sent in a
    slot only loses its TX_EN pre-assert), and TX stays low after a break in
    arbitration mode.
    Covered by test_tx_keep_low.
2026-11-13 Simplify the core and the tests, note the arbitration rate limit
    cd_tx_ser has a single TX_PRE state again, TX_EN is withheld there
    before a break in BS mode. cd_tx_bytes takes the last byte as the one
    after the first CRC byte: one data_len compare less, on the critical
    path of the core in the yosys/nextpnr flow. cd_csr keeps INT_FLAG_H in
    the top byte of the shift register instead of a second snapshot, so
    bytes after the third of an INT_FLAG_L burst read INT_FLAG_H instead of
    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
2026-11-14 Leave a spare clock for single-port RAM in the TX byte fetch and QSPI reads
    With CD_SPRAM_ONLY a read that meets a write is done one clock later.
    Two readers had no clock to spare: at 3 clocks per bit the first clock
    of bit 0 could still carry the previous byte while the host wrote the
    other TX page, and QSPI reads above 2/3 of the system clock could
    return a byte twice while a frame was received.
    With CD_SPRAM_ONLY cd_tx_bytes gives the next address to the RAM in the
    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
